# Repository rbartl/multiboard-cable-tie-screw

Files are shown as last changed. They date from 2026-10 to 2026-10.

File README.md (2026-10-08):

# Under-Desk Cable Tie für Multiboard

Kabelhalter zum Einschnappen ins Multiboard-Multihole — funktionale Nachbildung von
[Under-Desk Cable Tie for OpenGrid System](https://makerworld.com/en/models/1908305-under-desk-cable-tie-for-opengrid-system),
bei der der OpenGrid-Fuß durch einen Multiboard-Snap ersetzt ist.

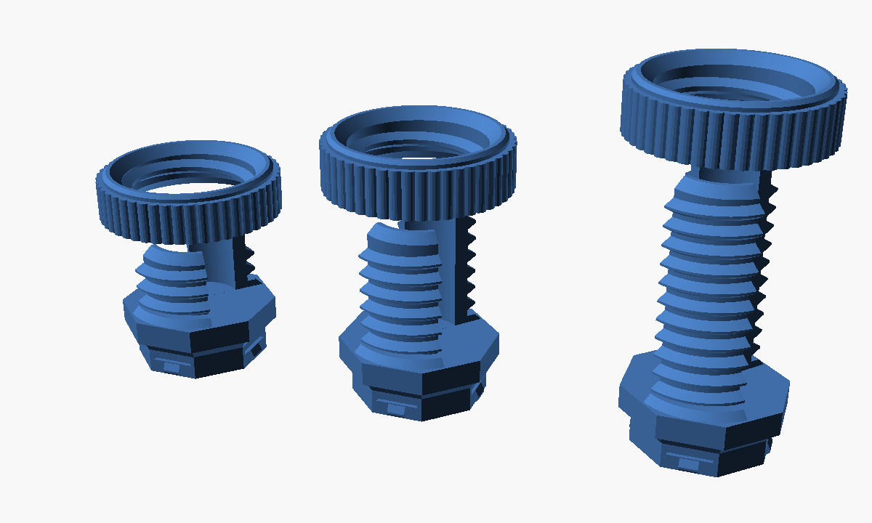
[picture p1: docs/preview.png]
S, M und L mit aufgesetzter Rändelmutter


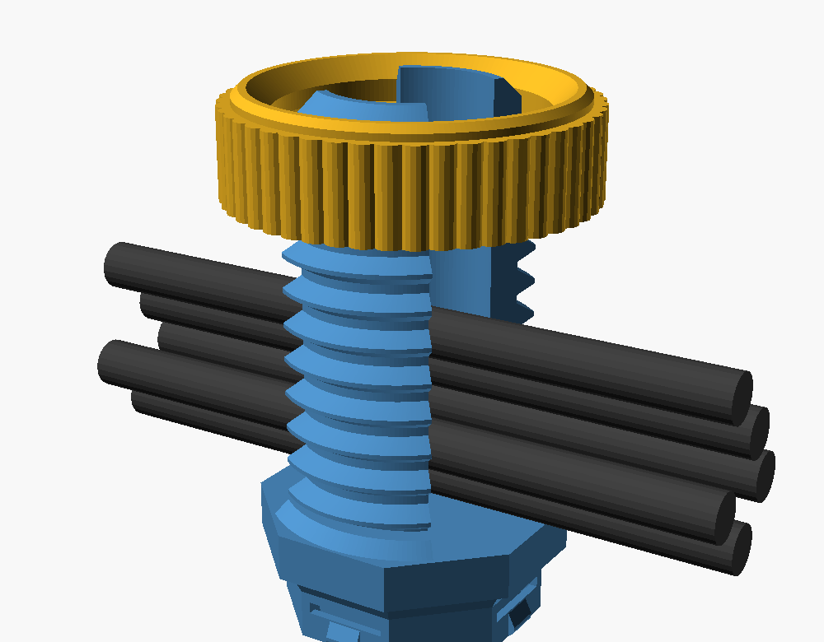
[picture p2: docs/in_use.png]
L mit fünf Kabeln, die mittig durch den Topf laufen


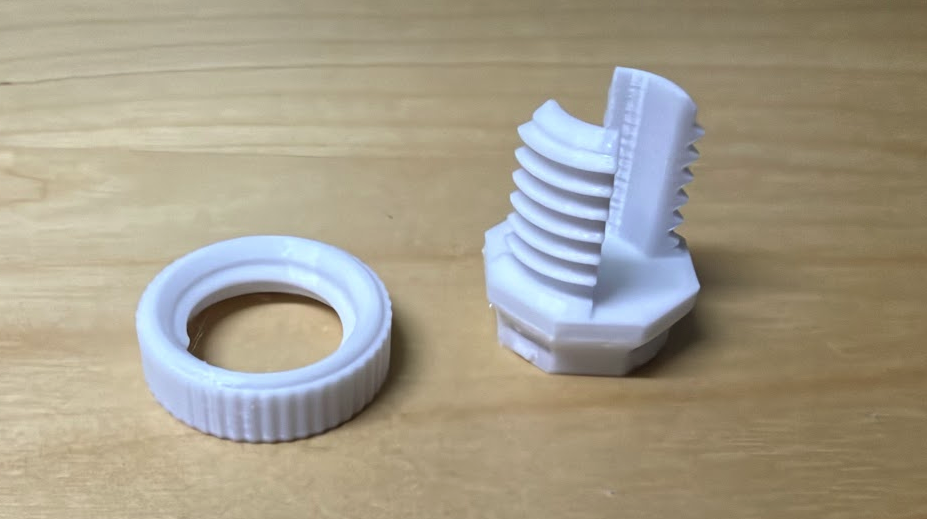
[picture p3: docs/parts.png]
Body und Mutter einzeln: Gewindepost mit den zwei Fenstern, Rändelmutter


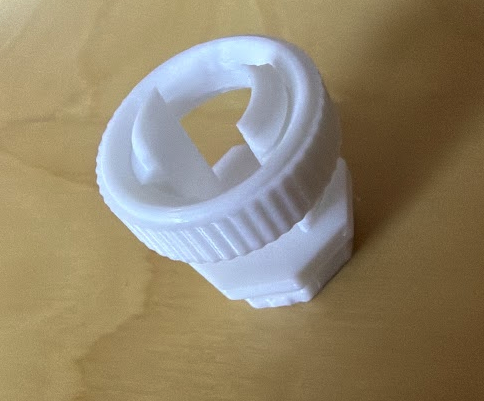
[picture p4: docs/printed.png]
Gedrucktes Teil mit aufgeschraubter Mutter


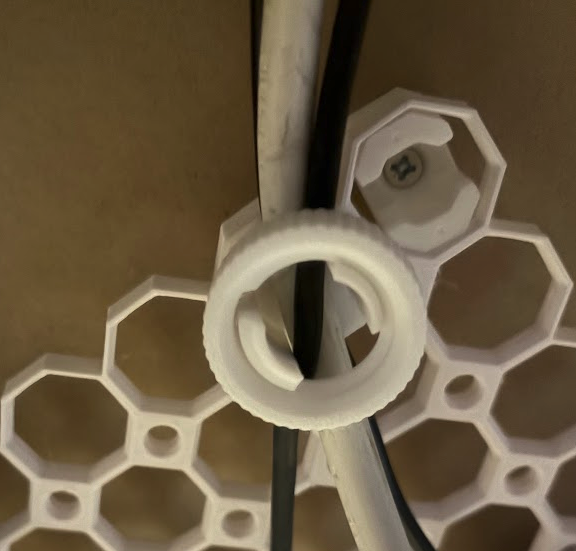
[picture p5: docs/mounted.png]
Unter dem Schreibtisch am Multiboard montiert, mit zwei Kabeln


## Funktion

Gewindetopf mit zwei gegenüberliegenden Fenstern (je 100°): die Kabel laufen
mittig geradeaus durch den Topf und auf der anderen Seite wieder raus. Rändelmutter
von oben über die Kabel herunterschrauben — der Mutternring sperrt beide Fenster,
die Kabel können nicht mehr raus.

Mehrere Kabel stapeln sich übereinander im Topf. Deshalb unterscheiden sich die
Größen vor allem in der **Höhe**, nicht im Durchmesser — genau wie beim Original.

Alle drei brauchen nur **eine** Multiboard-Zelle.

| Größe | Kabel | Posthöhe | Grundplatte | Snaps |
|---|---|---|---|---|
| S | 1–2 | 12 mm | 1 Zelle (25 × 25 mm) | 1 |
| M | ~5 | 22 mm | 1 Zelle (25 × 25 mm) | 1 |
| L | bis ~10 | 36 mm | 1 Zelle (25 × 25 mm) | 1 |

Gleich bei allen: Gewinde-Ø 22 mm, Innen-Ø 14,0 mm, nutzbare Kanalbreite 10,7 mm,
Steigung 3 mm, radiales Spiel Mutter/Gewinde 0,3 mm, Wandstärke unter dem
Gewindegrund 2,4 mm, Hohlkehle am Postfuß 1,2 mm.

Der Gewinde-Ø ist durch die 25-mm-Zelle begrenzt: die Grundplatte folgt der
Multiboard-Zellenkontur (Achteck, 25 mm Schlüsselweite, 7,32 mm Eckfase), damit das
Teil wie übliche Multiboard-Teile sauber auf dem Raster sitzt.

## Drucken

STLs liegen fertig in `stl/`. Alle Teile drucken ohne Support:

- **Body**: Snap nach unten auf das Bett, Gewindepost nach oben
- **Mutter**: flach, Gewinde selbsttragend
- 0,16 mm Layer (0,12 mm für saubereres Gewinde), 3 Wände, 20–25 % Infill
- PLA oder PETG

Sitzt die Mutter zu stramm, `thread_slop` erhöhen (Default 0,15) und neu rendern.

## Montage

Snap ins Multihole drücken und ca. 1/8 Umdrehung drehen, bis die vier Bumpouts im
Boardgewinde greifen. Achteckig ⇒ 8 Ausrichtungen in 45°-Schritten.

## Selbst rendern

Braucht [OpenSCAD](https://openscad.org) und [BOSL2](https://github.com/BelfrySCAD/BOSL2)
in `~/Documents/OpenSCAD/libraries/`.

```sh
./build.sh
```

Parameter in `src/cable_tie.scad`: `size` (S/M/L), `part` (all/body/nut),
`slot_a` (Fensterwinkel), `thread_d`, `thread_slop`.

## Passform

Die Snap-Geometrie wurde gegen eine aus den offiziellen Multiboard-Maßen generierte
Board-Zelle geprüft: ausschließlich die vier Bumpouts greifen ins Boardgewinde
(0,87 mm³ Überdeckung), sonst kollisionsfrei.

## Credits & Lizenz

Die Snap-Geometrie (`src/multiboard_snap.scad`, daraus gerendert
`src/multiboard_snap.stl`) stammt aus
[MultiConnectOpenSCAD](https://github.com/cschneid/MultiConnectOpenSCAD) von
Andy Levesque, mit Credit an @David D (Multiconnect) und Jonathan / Keep Making
(Multiboard).

Das gesamte Projekt steht deshalb unter
[CC BY-NC-SA 4.0](https://creativecommons.org/licenses/by-nc-sa/4.0/) **und** der
[Multiboard License](https://multibuild.io/license); es gilt jeweils die strengere
Regel. Volltext und Attribution in [`LICENSE`](LICENSE). Kurz:

- Für den Eigenbedarf drucken und nutzen: erlaubt.
- Remixe teilen: erlaubt, unter denselben Bedingungen und mit Namensnennung.
- Kommerzielle Nutzung, auch der Verkauf von Drucken: **nicht** erlaubt.

Kein offizielles Multiboard-Teil; nicht mit MULTIBOARD LTD verbunden oder von
ihnen unterstützt.

Hinweis: `multiboard_snap.scad` braucht eine BOSL2-Version von vor 2024-08
(`spin` als Vektor). Deshalb liegt die daraus gerenderte Geometrie als STL bei;
`src/cable_tie.scad` importiert das STL und läuft mit aktuellem BOSL2.

Die Idee des Mechanismus stammt vom oben verlinkten OpenGrid-Modell; die Geometrie
hier ist eigenständig konstruiert.

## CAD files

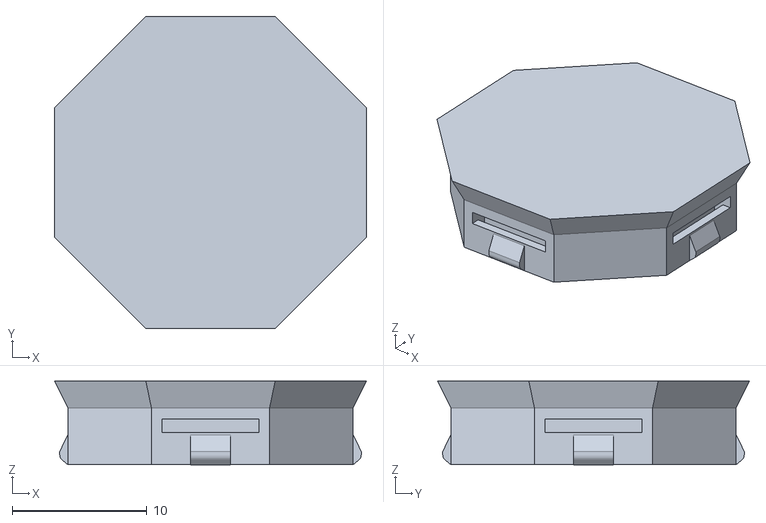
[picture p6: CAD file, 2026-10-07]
src/multiboard_snap.stl
23.1 x 23.1 x 6.19

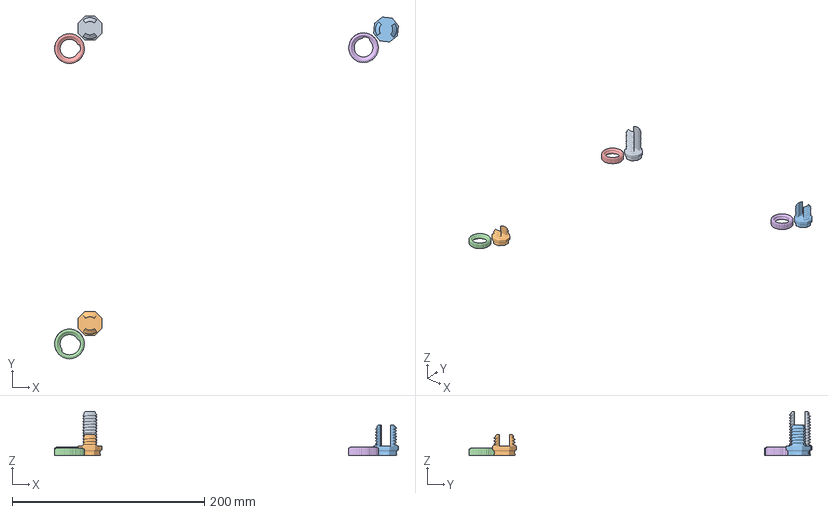
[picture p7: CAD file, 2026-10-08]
stl/cable_tie_multiboard.3mf
357.8 x 356.6 x 46.1 mm
cable_tie_L_body.stl
cable_tie_S_body.stl
cable_tie_M_body.stl
cable_tie_S_nut.stl
cable_tie_L_nut.stl
cable_tie_M_nut.stl

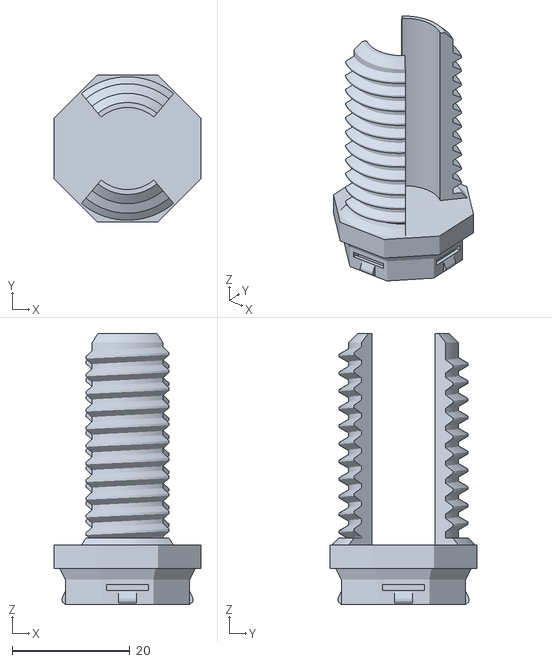
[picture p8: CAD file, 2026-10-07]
stl/cable_tie_L_body.stl
25.0 x 25.0 x 46.1

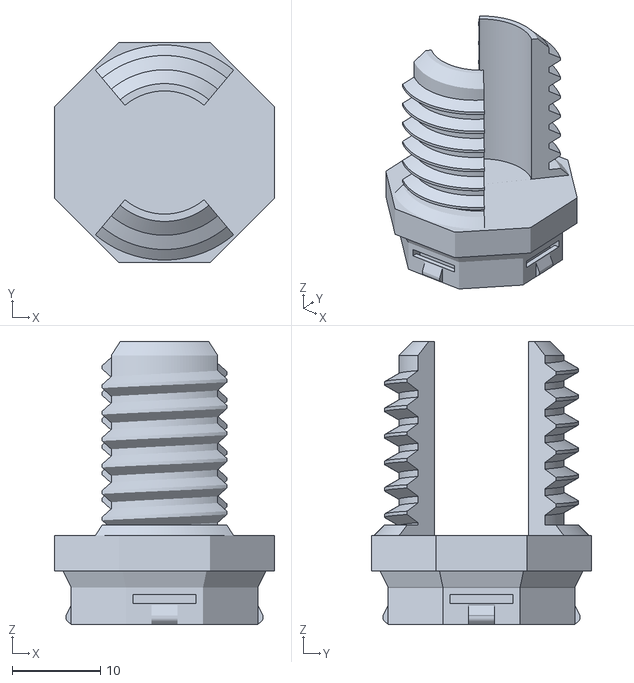
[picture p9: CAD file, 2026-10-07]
stl/cable_tie_M_body.stl
25.0 x 25.0 x 32.1

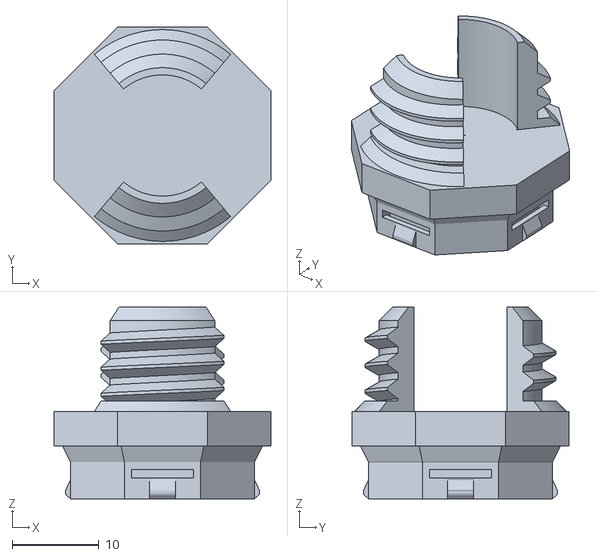
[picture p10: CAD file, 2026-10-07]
stl/cable_tie_S_body.stl
25.0 x 25.0 x 22.1

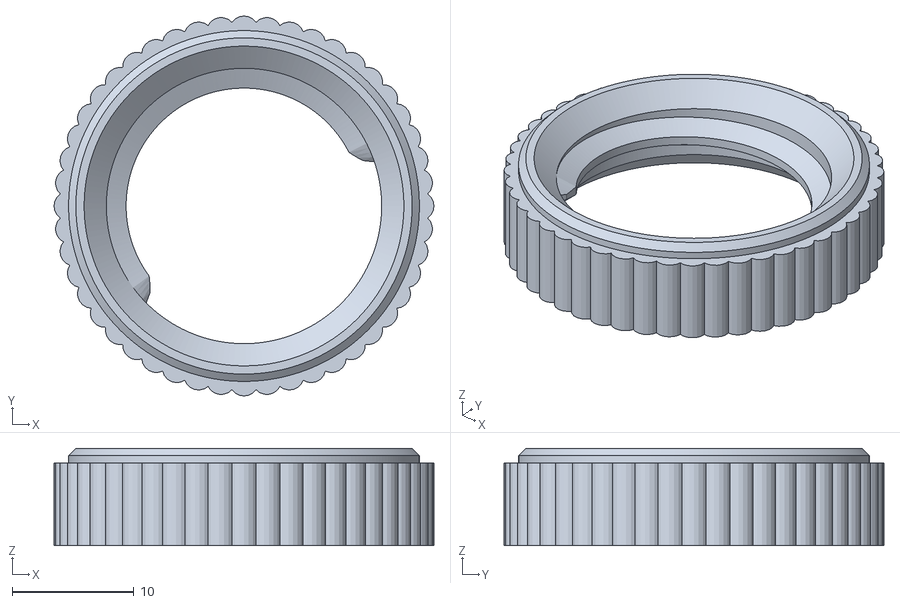
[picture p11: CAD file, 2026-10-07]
stl/cable_tie_S_nut.stl
31.2 x 31.2 x 8.00

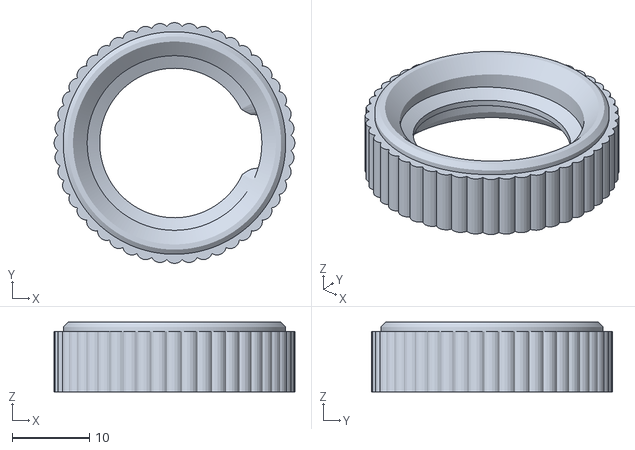
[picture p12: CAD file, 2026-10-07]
stl/cable_tie_M_nut.stl
31.2 x 31.2 x 9.00

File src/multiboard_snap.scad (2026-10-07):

/*Created by Andy Levesque
Credit to 
    - @David D on Printables for Multiconnect
    - Jonathan at Keep Making for Multiboard
Licensed Creative Commons 4.0 Attribution Non-Commercial Sharable with Attribution
This file also adopts the Multiboard License https://www.multiboard.io/license
All adaptations must have attribution and follow the more restrictive of the two licenses. 
*/

/* Vendored from https://github.com/cschneid/MultiConnectOpenSCAD
   (Modules/snapConnector.scad). Demo geometry and its customizer
   variables were stripped so the file works as a library via `use <>`. */

include <BOSL2/std.scad>
include <BOSL2/rounding.scad>

//snap connector https://a360.co/3AI9ZVW

module snapConnectBacker(offset = 0, holdingTolerance=1, anchor=CENTER, spin=0, orient=UP){
    attachable(anchor, spin, orient, size=[11.4465*2, 11.4465*2, 6.17+offset]){ 
    //bumpout profile
    bumpout = turtle([
        "ymove", -2.237,
        "turn", 40,
        "move", 0.557,
        "arcleft", 0.5, 50,
        "ymove", 0.252
        ]   );

    down(6.2/2+offset/2)
    union(){
    diff("remove")
        //base
            oct_prism(h = 4.23, r = 11.4465, anchor=BOT) {
                //first bevel
                attach(TOP, BOT, shiftout=-0.01) oct_prism(h = 1.97, r1 = 11.4465, r2 = 12.5125, $fn =8, anchor=BOT)
                    //top - used as offset. Independen snap height is 2.2
                    if (offset > 0)
                        attach(TOP, BOT, shiftout=-0.01) oct_prism(h = offset, r = 12.9885, anchor=BOTTOM);
                        //top bevel - not used when applied as backer
                        //position(TOP) oct_prism(h = 0.4, r1 = 12.9985, r2 = 12.555, anchor=BOTTOM);
            
            //end base
            //bumpouts
            attach([RIGHT, LEFT, FWD, BACK],LEFT, shiftout=-0.01)  color("green") down(0.87) fwd(1)scale([1,1,holdingTolerance])offset_sweep(path = bumpout, height=3, spin=[0,270,0]);
            //delete tools
            //Bottom and side cutout - 2 cubes that form an L (cut from bottom and from outside) and then rotated around the side
            tag("remove") 
                 align(BOTTOM, [RIGHT, BACK, LEFT, FWD], inside=true, shiftout=0.01, inset = 1.6) 
                    color("lightblue") cuboid([0.8,7.161,3.4], spin=90*$idx)
                        align(RIGHT, [TOP]) cuboid([0.8,7.161,1], anchor=BACK);
            }
    }
    children();
    }

    //octo_prism - module that creates an oct_prism with anchors positioned on the faces instead of the edges (as per cyl default for 8 sides)
    module oct_prism(h, r=0, r1=0, r2=0, anchor=CENTER, spin=0, orient=UP) {
        attachable(anchor, spin, orient, size=[max(r*2, r1*2, r2*2), max(r*2, r1*2, r2*2), h]){ 
            down(h/2)
            if (r != 0) {
                // If r is provided, create a regular octagonal prism with radius r
                rotate (22.5) cylinder(h=h, r1=r, r2=r, $fn=8) rotate (-22.5);
            } else if (r1 != 0 && r2 != 0) {
                // If r1 and r2 are provided, create an octagonal prism with different top and bottom radii
                rotate (22.5) cylinder(h=h, r1=r1, r2=r2, $fn=8) rotate (-22.5);
            } else {
                echo("Error: You must provide either r or both r1 and r2.");
            }  
            children(); 
        }
    }
    
}

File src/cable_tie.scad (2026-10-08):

/*
  Under-desk cable tie for the Multiboard system.

  Functional re-interpretation of "Under-Desk Cable Tie for OpenGrid System"
  (makerworld.com/en/models/1908305) with the OpenGrid foot replaced by a
  Multiboard multihole snap.

  Snap geometry by Andy Levesque (MultiConnectOpenSCAD), credit to @David D
  (Multiconnect) and Jonathan at Keep Making (Multiboard).
  CC BY-NC-SA 4.0 + Multiboard License (https://multibuild.io/license; see LICENSE).
*/

include <BOSL2/std.scad>
include <BOSL2/threading.scad>

/* [Model] */

// Cable capacity
size = "M"; // [S:small - 1-2 cables, M:medium - ~5 cables, L:large - up to ~10 cables]
// Which part to render
part = "all"; // [all, body, nut]

/* [Fit] */

// Printer tolerance for the nut thread. Increase if the nut is too tight.
thread_slop = 0.15;

/* [Hidden] */

$fa = 1;
$fs = 0.4;
$slop = thread_slop;

// Multiboard grid. A cell is a 25 mm square with its corners cut back by
// cell_chamfer, which is the outline every plate here follows.
cell = 25;
cell_chamfer = (cell - cell / (1 + 2 * cos(45))) / 2; // 7.3223

// The sizes differ mainly in post height: cables stack up inside the pot.
// size -> [post height, plate cells in y, nut height]
spec = size == "S" ? [12, 1, 8]
     : size == "L" ? [36, 1, 9]
     :               [22, 1, 9];

post_h    = spec[0];
plate_y   = spec[1];
nut_h     = spec[2];
snaps     = plate_y;

// Thread diameter is capped by the 25 mm cell so the plate stays grid-sized.
thread_d = 22;
pitch    = 3;
// Measured depth of the BOSL2 thread profile at this pitch; the bore has to
// clear it, otherwise the wall under the thread root ends up paper thin.
thread_depth = 1.62;
wall     = 2.4;
base_t   = 4;
// Fillet where the two posts meet the plate — that root is where they bend.
root_fillet = 1.2;
bore_d   = thread_d - 2 * (thread_depth + wall);
nut_od   = thread_d + 8;
// Opening angle of each of the two cable windows.
slot_a   = 100;
// The vendored snap mesh spans z 0..6.19; sink it 0.1 into the plate so the
// two solids actually merge.
snap_z   = 6.09;

if (part == "all") {
    body();
    translate([0, plate_y * cell / 2 + nut_od / 2 + 4, 0]) nut();
} else if (part == "body") {
    body();
} else if (part == "nut") {
    nut();
}

module body() {
    difference() {
        union() {
            for (i = [0:snaps - 1])
                back((i - (snaps - 1) / 2) * cell) down(snap_z)
                    import("multiboard_snap.stl", convexity = 6);
            plate();
            up(base_t - 0.01)
                threaded_rod(d = thread_d, l = post_h + 0.01, pitch = pitch,
                             bevel1 = false, bevel2 = true, anchor = BOTTOM);
            up(base_t - 0.01)
                cyl(d1 = thread_d + 2 * root_fillet, d2 = thread_d,
                    h = root_fillet + 0.01, anchor = BOTTOM);
        }
        // cable bore
        up(base_t) cyl(d = bore_d, h = post_h + 1, anchor = BOTTOM);
        // through channel: a window on each side so a cable passes straight
        // through the centre instead of dead-ending against the back wall
        for (a = [0, 180])
            zrot(a) up(base_t - 0.01) sector_cut(slot_a, post_h + 1.02, thread_d);
    }
}

// Plate following the Multiboard cell outline, plate_y cells long.
module plate() {
    w = cell / 2;
    l = plate_y * cell / 2;
    c = cell_chamfer;
    linear_extrude(base_t)
        polygon([
            [ w - c, -l], [ w, -l + c], [ w, l - c], [ w - c, l],
            [-w + c,  l], [-w,  l - c], [-w, -l + c], [-w + c, -l],
        ]);
}

module sector_cut(ang, h, r) {
    linear_extrude(h)
        polygon([[0, 0], for (t = [-ang / 2 : ang / 32 : ang / 2]) [r * cos(t), r * sin(t)]]);
}

module nut() {
    knurl_r = 1.2;
    knurls = round(nut_od * 1.6);
    difference() {
        union() {
            cyl(d = nut_od - knurl_r, h = nut_h, chamfer = 0.6, anchor = BOTTOM);
            for (i = [0:knurls - 1])
                zrot(i * 360 / knurls) right((nut_od - knurl_r) / 2)
                    cyl(d = knurl_r * 2, h = nut_h - 1.2, anchor = BOTTOM);
        }
        up(-0.01) threaded_rod(d = thread_d, l = nut_h + 0.02, pitch = pitch,
                               internal = true, bevel = true, anchor = BOTTOM);
    }
}

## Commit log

2026-10-07 Add Multiboard under-desk cable tie
    Re-interprets the OpenGrid cable tie for Multiboard: a threaded pot with
    two opposing 100-degree windows so cables run straight through the centre,
    closed off by a knurled nut. Mounted with a Multiboard multihole snap on a
    plate that follows the 25 mm cell outline.
    Sizes differ in post height rather than diameter, since cables stack inside
    the pot and the 25 mm cell caps the thread diameter.
    Snap geometry vendored as STL because its source needs a pre-2024-08 BOSL2.
    [cable_tie.scad, cable_tie_L_body.stl, cable_tie_L_nut.stl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]
2026-10-07 Fit the large size onto a single Multiboard cell
    The large version used a two-cell plate with two snaps. All three sizes
    now share the same one-cell octagonal plate and differ only in post
    height.
    [cable_tie.scad, cable_tie_L_body.stl]
2026-10-08 Add LICENSE and spell out licensing in the README
    The vendored snap geometry is CC BY-NC-SA 4.0 plus the Multiboard
    License, so the whole project inherits both. Add the full CC text with
    an attribution header, summarize the terms in the README, and point the
    Multiboard License links at its current URL.
    [cable_tie.scad]
2026-10-08 Add photos of the printed and mounted cable tie
2026-10-08 added 3mf, picture
    [cable_tie_multiboard.3mf]
